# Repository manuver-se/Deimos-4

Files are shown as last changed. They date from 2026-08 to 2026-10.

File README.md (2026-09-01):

# Deimos-4 | Analog, DIY rhythm machine

Welcome to the official repository for the **Deimos-4**, a DIY, analog 4-voice drum machine with step-sequencer powered by an Arduino Nano.

Designed for both live jamming and having lots of fun, the Deimos-4 combines classic analog circuitry based on the original 606 and 808 circuits, a 16-step sequencer, an intuitive interface, basic sync out connectivity, and an expansion header for future expansions.

A7C14604-E1E4-4C48-A52F-A848609FFAB7_1_105_c

---

## Overview & Features

* **4 analog drum voices:** Dedicated circuits for Kick, Snare, Closed Hi-Hat (CHH), and Open Hi-Hat (OHH) with choke logic for the hihats. The decay and pitch for kick and snappy and pitch for snare are changeable. The levels of each individual drum voice can also be adjusted with trimpots.
* **16-step sequencer:** Divided across 4 pages (4 steps per page) with per-step pattern memory. There are controls for tempo, swing and sequencer length. Individual drum voices are mutable while the sequence is running.
* **Dual operating modes:**
  * **Live mode:** Finger-drum live or over a running background sequence.
  * **Sequencer mode:** Full step-editing control per voice and per step.
* **EEPROM memory:** Automatic pattern saving using the internal EEPROM memory from the Arduino Nano.
* **Sync out:** Jumper configurable sync out with **opto-isolated S-trig** (short-to-ground triggers used for some vintage synths) or **direct 5V V-trig** (for most modern gear, eurorack).

---

## Test points & Expansion header

For DIY builders, modders, and audio hackers, the Deimos-4 PCB includes dedicated test points for diagnostics as well as an onboard expansion header for custom hardware modifications.

### Onboard test points
* **Noise generators:** Dedicated test/tap points for both **White Noise (noice noize)** and **Metallic Noise (Beehive(ing)_Noizzze)** (used for snare snappy and hihat circuits respectively) 
* **Hidden tom circuit:** Test/tap point for the snare without snappy
* **Voltage rails:** Testpoints for 9V, digital 5V, 4.5V and GND rails
* **Individual voice tap points:** Test/tap points for the raw audio signal of each drum voice (Kick, Snare, CHH, OHH) before it reaches the master summing stage.
* **Triggers:** 4 testpoints for triggering drum voices: Kick trigger (BD_TR), Snare trigger (SN_TR), Hihat trigger (to trigger open hihat; HH_TR) and a gate testpoint (HH_GT) that together with the Hihat trigger, triggers the closed hihat.

### Hardware expansion header
The PCB design also features an 8 pin header designed for hardware expansions and modifications. This connector includes:
* **Separate outs:** Tap each drum voice individually to route them to dedicated external audio jacks, outboard effects, or separate mixer channels.
* **Power rails:** Exposes internal power rails (9V, 4.5V and GND) to power future expansion boards or external mod circuits.
* **Master out & To jack input:** Access to master out and jack input. These two pins should be connected by default.

## Manual & Documentation

For detailed information on drummachine history, kit assembly or operating manual, please refer to the temporary user manual included in the repository. For now there only is a version Dutch, but the English version is coming soon.

* **[Handleiding-ned.pdf]** 

---

## Terms of use & Licensing

If you made it until here, I thank you for your interest in the Deimos-4 drummachine project! Please take a moment to review the guidelines regarding the hardware, software, and documentation shared in this repository:

* **Firmware & Documentation:** All source code, schematics, and documentation provided here are free for personal, educational, and non-commercial use. You are welcome to study, modify, and flash the code for your own personal DIY builds.
* **PCB design files:** Please note that the KiCad PCB layout files and Gerbers aren't included in this repository and will not be released publicly. The Deimos-4 hardware design is proprietary and will be manufactured and sold as a commercial DIY kit in the future.
* **Commercial restriction:** You may not use the documentation, code, or hardware schematics from this repository for any commercial purposes, product manufacturing, or resale without explicit permission.

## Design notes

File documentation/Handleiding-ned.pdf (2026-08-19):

## Deimos-4 DIY, Analog rhythm machine

## Part of the Manuverse

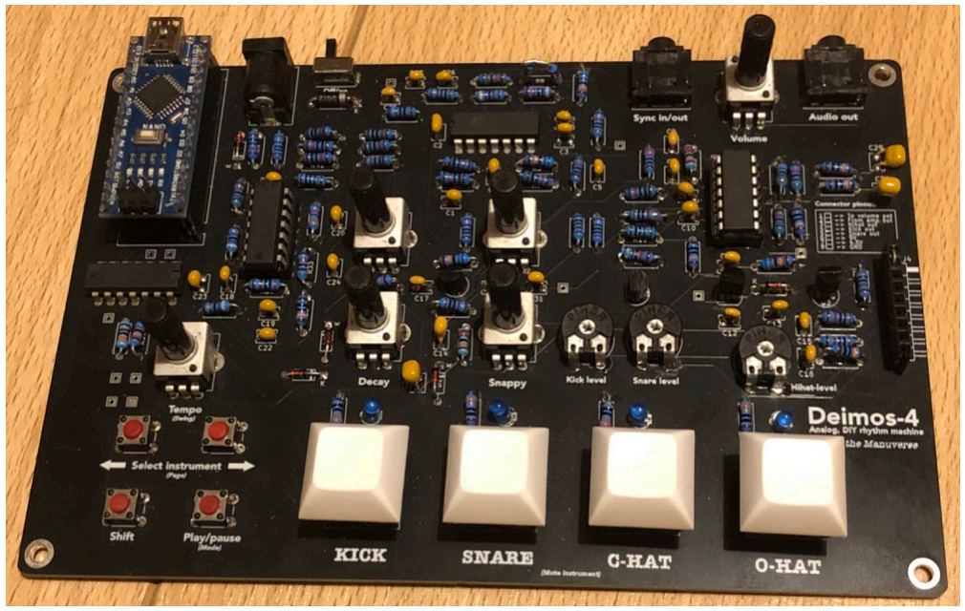
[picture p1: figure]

# Handleiding

# Inhoud

## 1. Korte geschiedenis van de drummachine • De 1e drummachine (3)

- Zoektocht naar een ritmische begeleiding (3)
- Eerste programmeerbare drummachine (4)
- Gouden decennium (4)
- Drummachines van toen naar nu (5)

## 2. Assemblage van de kit • BOM (6)

- Voorbeeld (voor een condensator) (6)
- BOM (voor echt!!!) (7)
- Voorbeeld (voor een weerstand) (8)
- Diodes, transistors en IC chips (8)
- Grote en mechanische componenten (9)

## 3. Bediening van de drummachine • De Knoppen & De Koplampen (10)

- Live Modus vs. Sequencer Modus (10)
- Tempo, Swing & ‘Catch-Up’ (12)
- Extra Pro-Tricks voor de Geavanceerde Beatmaker (12)
- Onder voorbehoud (Rev2.1): De Sync-Out (Jumper Instellingen op de PCB) (13)

## 4. Documentatie (14)

# Korte geschiedenis van de drummachine

De drummachine is vandaag de dag niet meer weg te denken uit genres als hiphop, pop, techno, dance, R&B en vele andere. De opzwepende ritmes die ze kunnen produceren met hun karakteristieke geluid zijn geliefd bij vele muzikanten en producers. In dit hoofdstuk gaan we zo’n 100 jaar terug in de tijd om te kijken hoe drummachines zijn geëvolueerd tot de elektronische percussie-instrumenten die we nu kennen.

### De 1e drummachine

De oorsprong van de drummachine brengt ons opvallend
ver terug in de tijd, naar het jaar 1930 om precies te zijn. De Amerikaanse avant-garde componist Henry Cowell was op zoek naar een manier om complexe, polyritmische patronen te spelen die voor een menselijke muzikant vrijwel onmogelijk waren. Hij schakelde de hulp in van Leon Theremin, de uitvinder van de gelijknamige Theremin, om samen de ‘rhythmicon’ (Fig. 1.1) te ontwerpen. Dit indrukwekkende instrument, dat door velen wordt beschouwd als de allereerste drummachine ter wereld,
werkte zowel optisch als mechanisch door middel van een
draaiende schijf met gaatjes die werd uitgelezen door

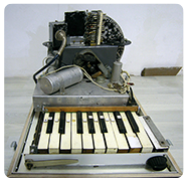
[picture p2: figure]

lichtsensors die de plotse lichtinval bij passage van een gaatje registreerden. Hoewel de Rhythmicon zijn tijd ver vooruit was, duurde het tot 1959 voordat de eerste commerciële drummachine op de markt verscheen: de Wurlitzer Sideman. In tegenstelling tot moderne drummachines was dit een gigantische, houten kast die werkte met vacuümbuizen en een roterende schijf met pinnen die functioneerde als een soort muziekdoos. Hij bevatte tien elektronisch gegenereerde percussiegeluiden en bood voorgeprogrammeerde ritmes zoals de ‘waltz’ en de ‘cha cha’.

### Zoektocht naar een ritmische begeleiding

In het begin van de jaren zestig was een jonge Japanse uitvinder, Ikutaro Kakehashi, diep geïntrigeerd geraakt door de Wurlitzer Sideman. Hij richtte Ace Electronic Industries op en begon met de ontwikkeling van kleinere ritmeboxen. Dit leidde in 1967 tot een enorme doorbraak: de FR-1 Rhythm Ace. Het was de allereerste ritme-machine op de markt met een ritmespeler en bovenal: transistor gebaseerde circuits in plaats van de plaatsnemende en zware vacuüm tubes.
Dit transistorontwerp was een gigantische stap voorwaarts in betrouwbaarheid en draagbaarheid. De Rhythm Ace was enorm populair, in zo'n grote mate dat de Hammond Organ Company besloot het systeem te adopteren en zelfs in te bouwen in hun orgels! Kakehashi ontwierp na de FR-1 nog tal van andere gelijkaardige drummachines onder Ace Electronic die telkens ook fungeerden als ritmische begeleiding voor organisten en muzikanten.

Fig. 1.1: Rhythmicon
Andrey Smirnov via asmir.info

### Eerste programmeerbare drummachine

Hoewel de vroege transistor-apparaten een succes waren, konden muzikanten alleen meespelen met voorgeprogrammeerde ritmes. De wens om zelf de controle te nemen leidde in 1972 tot de Eko ComputeRhythm (Fig. 1.2), die wordt beschouwd als de eerste echt programmeerbare drummachine ter wereld. Binnen een volledig analoog circuit stelde de ComputeRhythm muzikanten in staat om zelf zes verschillende drumvoices te programmeren in een raster van 16 stappen. Deze machine was zijn tijd zo ver vooruit dat er vandaag de dag wereldwijd naar schatting nog maar 15 werkende exemplaren van bestaan.

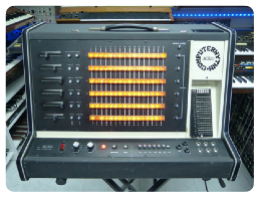
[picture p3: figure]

### Gouden decennium

De overgang van de jaren 70 naar 80 markeert een ware explosie aan innovatie voor elektronische instrumenten, zowel voor drummachines als synthesizers. Herinner je je Ikutaro Kakehashi nog? In 1972 richtte hij het inmiddels legendarische merk Roland Corporation op.
CR-78: Met de introductie van de Roland CR-78 in 1978 werd voor het eerst chiptechnologie gebruikt, wat muzikanten in staat stelde patronen te programmeren én op te slaan in het geheugen. Dit iconische apparaat kreeg grote bekendheid door artiesten als Blondie en Phil Collins, die de unieke sound omarmden.
TR-808: Twee jaar later kwam de Roland TR-808 Rhythm Composer op de markt. Met zijn zware, diepe analoge kickdrum en karakteristieke cowbell klonk de 808 niet echt als een realistisch drumstel, wat er initieel voor zorgde dat het apparaat flopte. Toen de 808 echter jaren later goedkoop op de tweedehandsmarkt belandde, pikten slaapkamerproducers het op en werd de TR-808 dé ruggengraat van hiphop en elektronische dansmuziek. Het is ook diezelfde 808 (samen met de TR606, een versimpelde en goedkopere versie van de 808) die de inspiratie vormde voor de Deimos-4.
LinnDrum: Tegelijkertijd (in 1980) introduceerde de Amerikaanse ingenieur Roger Linn de Linn LM-1, de allereerste drummachine die gebruikmaakte van digitale samples (akoestische drumopnames). Dit resette de industrie: ineens kregen drummachines een realistische klank. Zijn opvolger, de goedkopere LinnDrum uit 1982, domineerde vrijwel de volledige popmuziek uit de vroege jaren 80 en is te horen op monsterhits van o.a. Prince en The Human
League.
Oberheim DMX (Fig. 1.3): Kort daarop kwam
synthesizerpionier Oberheim met de concurrent: de Oberheim DMX. Dit 12-bit sample-based instrument klonk luchtiger en realistischer, wat het geluid definieerde van tracks als New Order's Blue Monday.
Linn 9000: In 1984 zette Roger Linn een nieuwe standaard met de Linn 9000, dat fungeerde als de eerste geïntegreerde digitale drummachine met een
ingebouwde MIDI-sequencer en drukgevoelige rubberen

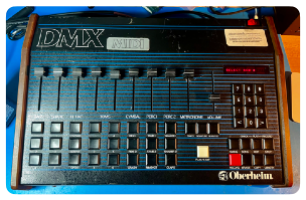
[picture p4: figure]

pads, functies die later industriestandaarden zouden worden.

Fig. 1.3: Oberheim DMX
wikipedia.org/wiki/Oberheim_DMX

Fig. 1.2: EKO
Computerhythm MKIII
reverb.com/news

TR-909: In 1983 reageerde Roland met de TR-909. Waar eerdere Roland drummachines volledig analoog klank opwekten, gebruikte de 909 een hybride systeem: analoge circuits voor de kick, snare, rim, clap en toms gecombineerd met digitale samples voor de cymbals en hi-hats. Helaas flopte deze drummachine ook wanneer deze op de markt kwam omdat iedereen wild was van de nieuwe, digitale drummachines omdat ze veel realistischer klonken. Maar naar klassieke Roland traditie zijn er jonge muzikanten die enkele jaren later 909’s tegenkwamen op de tweedehandsmarkt om nieuwe genres als techno en house uit de grond te stampen.
Akai MPC: Aan het einde van het decennium, in 1988, bundelde Roger Linn zijn krachten met het Japanse Akai. Het resultaat was de Akai MPC60. Dit geïntegreerde systeem fungeerde als sampler, drummachine en sequencer in één, uitgerust met de beroemde 4x4 grid van responsieve pads.

### Drummachines van toen naar nu

Toen computers in de late jaren 90 geavanceerder werden, nam de vraag naar hardware drummachines af ten gunste van software en VST-plugins. Toch blijft de drang naar een instrument dat je echt kan aanraken en bespelen reëel en het is vanuit dat opzicht dat ik besloot om de Deimos-4 te ontwerpen…

# Assemblage van de kit

Ziezo, nu je volledig bent ondergedompeld in de wonderlijke wereld van de drumcomputers, wil je er zelf waarschijnlijk ook één bouwen. Met deze kit heb je alvast alles in huis om een geweldige drummachine te bouwen.

### BOM

Een BOM (=Bill of Materials) is een lijst met een overzicht van alle componenten, hun aantallen en een referentie voor waar ze op de pcb horen geplaatst te worden. De handleiding voor de assemblage van de kit is grotendeels gebaseerd op de BOM, dus we gaan hier nog vaak op terugkomen. Op de volgende pagina staat ’m, maar om papierverspilling tegen te gaan gaan we al verder met instructies op deze pagina.
Eerst en vooral, hoe gebruik je zo’n BOM? Het is eigenlijk niet zo moeilijk eens je het door hebt. In de kolom ‘value/component’ staan alle componenten met hun eventuele waarde. In de kolom ernaast, ‘reference’, staan de pcb plaatscodes (geen idee hoe je dat in het Nederlands noemt, dus heb ik het maar een naam gegeven ;-) ). De meest rechtse kolom, ‘Qty’, zegt hoeveel er van een bepaald component zitten in deze kit.
De componenten staan min of meer in soldeervolgorde: begin met de keramische condensators, vervolgens de weerstanden, diodes en transistors, daarna de ic-chips en trimmers en om af te ronden de schakelaars, connectoren, potmeters en de Arduino.

### Voorbeeld (voor een condensator) (Fig. 2.1)

Ik stel voor dat we stap voor stap met behulp van de BOM een condensator plaatsen en solderen die kan dienen als voorbeeld voor de andere
condensatoren. We zullen de 2,2 nF’s plaatsen die bovenaan in de BOM staan. Bij ‘reference’ ernaast kan je zien dat ze op C12, C13 en C17 moeten komen.

Plaats de condensatoren op de juiste
plek. Je moet geen rekening houden

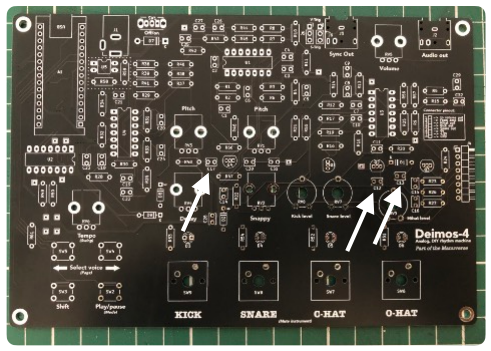
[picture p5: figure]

met polariteit aangezien alle condensatoren in deze kit keramisch zijn. Plooi de beentjes langs de achterkant om om te voorkomen dat ze eruit vallen wanneer je de pcb omdraait. Dan kan je de componenten vastsolderen en daarna de uiteinden die nog uitsteken afknippen met een kniptang. Opgelet: helaas heb ik door het plaatsen van bijbestellingen voor componenten soms andere formaten, waardoor niet elke condensator meteen ‘past’ op de footprint. In dit geval moet je de beentjes wat vervormen met een knijptang totdat ze wel passen, sorry…

Fig. 2.1: C12, C13 en C17 aangeduid op pcb

Deimos-4 Rev2.1 BOM

Value/component | Reference | Qty
2.2nF (Condensator) | C12,C13,C17 | 3
3.3nF (Condensator) | C15,C16,C26,C27 | 4
10nF (Condensator) | C25 | 1
15nF (Condensator) | C3,C4,C18 | 3
33nF (Condensator) | C5,C11 | 2
39nF (Condensator) | C8,C9 | 2
47nF (Condensator) | C30,C31 | 2
100nF (Condensator) | C1,C6,C7,C10,C19,C20,C21,C22,C23,C24 | 10
220nF (Condensator) | C2 | 1
1uF (Condensator) | C14 | 1
10uF (Condensator) | C28,C29,C32 | 3
47R (Weerstand) | R28 | 1
220R (Weerstand) | R14 | 1
330R (Weerstand) (1x Opt) | R51,R52,R53,R54,R58 | 5 (4)
680R (Weerstand) | R42 | 1
1K (Weerstand) (1x Opt) | R19,R21,R29,R43,R46,R55,R59,R61 | 8 (7)
3.3K (Weerstand) | R49 | 1
4.7K (Weerstand) | R45 | 1
10K (Weerstand) | R1,R2,R4,R6,R12,R36,R37,R38,R39,R40,R41 | 11
20K (Weerstand) | R11,R17,R23,R24,R26,R30,R47,R56 | 8
33K (Weerstand) | R31 | 1
47K (Weerstand) | R7,R16,R32 | 3
51K (Weerstand) | R33,R57 | 2
68K (Weerstand) | R25,R34,R44 | 3
100K (Weerstand) | R5,R9,R15,R18,R27,R35,R48 | 7
220K (Weerstand) | R13,R22 | 2
680K (Weerstand) | R3,R8,R10,R20,R50,R60 | 6
1N4148 (Diode) | D1,D2,D8,D9 | 4
1N5819 (Diode) | D7 | 1
LED (Diode) | D3,D4,D5,D6 | 4
2N3904 (Transistor) | Q1,Q2,Q3,Q4 | 4
LM324 (IC chip) | U1,U3 | 2
CD4066BE (IC chip) | U2 | 1
CD40106 (IC chip) | U4 | 1
LTV817 (IC chip) (Opt) | U5 | 1 (0)
10K (Potmeter-trimmer) | RV7,RV8,RV9 | 3
Power Switch (Schakelaar) | SW1 | 1
Menu Switches (Schakelaar) | SW2,SW3,SW4,SW5 | 4
Play Switches (Schakelaar) | SW6,SW7,SW8,SW9 | 4
Audio Jack (Connector) | J2,J3 | 2
8 Pin Conn (Connector) | J4 | 1
DC Jack (Connector) | J1 | 1
10K (B103) (Potmeter) | RV1,RV2,RV5,RV6 | 4
100K (A/B104) (Potmeter) | RV3 (B104),RV4 (A104) | 2
Arduino Nano (Microcontroller) | A1 | 1

### Voorbeeld (voor een weerstand)

Nu gaan we hetzelfde doen voor een weerstand. We zullen dit doen voor de weerstand van 47 Ohm die hoort bij footprint R28 (Fig. 2.2).

Begin met het omplooien van de beentjes van de weerstand zo dicht mogelijk bij de ‘body’ (het blauwe gedeelte). Zorg er uiteraard voor dat de twee beentjes in de zelfde richting zijn omgeplooid. Daarna kan je de weerstand op de juiste footprint
plaatsen. Ook nu kan je aan de
achterkant de beentjes omplooien om

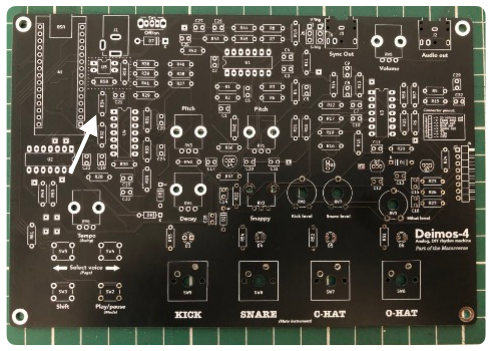
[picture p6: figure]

te voorkomen dat de weerstand eruit zou vallen. Soldeer en knip opnieuw de uiteinden af met een kniptang. (Het is nogal veel van hetzelfde, ik weet het ;-) )

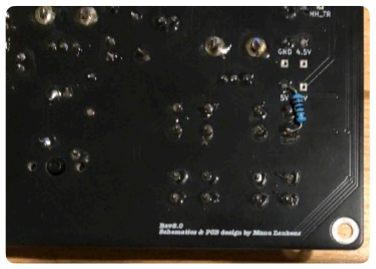
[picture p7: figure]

Opgelet (geldt enkel voor Rev2.0): R61 (1K)
staat niet op de pcb zoals die bij Rev2.1 erop
staat. Je moet deze weerstand dus nog zelf
solderen tussen 2 componenten zonder dat er een footprint voor voorzien is. Je soldeert hem tussen het 5V testpunt en een van de onderste twee beentjes van de knop met de pijl naar links. Bekijk ook even de afbeelding hiernaast om dit beter te zien (Fig. 2.3).

### Diodes, transistors en IC chips

Nu zijn we aangekomen bij het solderen van
componenten waarbij de polarisatie of m.a.w. de
richting van het component dat geplaatst wordt, belangrijk is. Ik ga dit voor elk van deze onderdelen even bespreken.
Diodes (Fig. 2.4) moeten ongeveer zoals weerstanden worden geplaatst, maar alleen is het belangrijk dat de kant met de zwarte streep (voor de 1N4148) of de witte streep (voor de 1N5819) van de diode overeen komt met de kant van de streep op de pcb. De platte kant van een LED moet overeenkomen met de kant van de vierkante soldeerpad.
Transistors moeten simpelweg geplaatst worden met de platte kant van de transistor aan dezelfde kant als de platte kant van de footprint. Let goed op dat er bij het solderen geen verbinding ontstaat tussen de beentjes van de transistor aangezien de

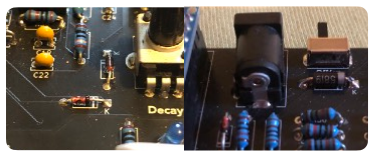
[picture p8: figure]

pads vrij dicht bij elkaar liggen voor de transistors.

Fig. 2.2: R28 aangeduid op pcb

Fig. 2.3: Gebridgede weerstand tussen 5V en onderste beentje knop naar links

Fig. 2.4: D8 en D9 (1N4148) met strepen overeenkomstig (links) D7 (1N5819) met streep
overeenkomstig (rechts)

Opgelet: helaas heb ik door het plaatsen van bijbestellingen voor componenten soms andere formaten, waardoor niet elke transistor meteen ‘past’ op de footprint. In dit geval moet je de beentjes wat vervormen met een knijptang totdat ze wel passen, sorry…

IC chips zijn al op voorhand door mij in hun socket gestoken om frustraties te voorkomen (ik heb al wel een paar chips kapot gedaan door ze in hun socket te steken… Misschien ligt dat aan mij, maar de sockets lijken nogal taai). Om de chips te plaatsen moet je goed opletten dat de kant met het hapje uit de chip overeen komt met de kant van het hapje uit de footprint. Let ook op dat je de soldeerbout niet te lang houdt op eenzelfde plaats om hitteschade aan de chip te voorkomen. Eventueel kan je in plaats van telkens de pin naast de juist gesoldeerde pin te solderen, de pin schuinover de juist gesoldeerde pin solderen. Als je het sync circuit op een Rev2.1 zou maken (dit circuit is voorlopig nog niet getest voor Rev2.1, maar ik ga dat zo snel mogelijk doen => op voorbehoud…), moet het bolletje op de LTV817 boven de rechthoekige soldeerpad komen.

### Grote en mechanische componenten

Alle componenten die nu nog overschieten zijn groot en/of (elektro)mechanisch. Ze wijzen zich grotendeels zelf uit om te solderen. Ik raad echter wel aan om min of meer de soldeervolgorde van de BOM te hanteren. Voor sommige componenten moet ik nog wel een klein beetje uitleg geven:
Voor de 8 pin connector is het heel belangrijk dat het blauwe tchoupke op de bovenste twee pinnen staat en niet op de onderste, anders kabaaaam => KORTSLUITING!!!
Op de onderkant van de potmeter staat een kleine ‘code’. In deze kit zitten er 4 B103’s (10K lineair), een B104 (100K lineair) en een A104 (100K logaritmisch). Het is belangrijk dat die op de juiste plek komen, maar dat spreekt natuurlijk voor zich. In de BOM heb ik ook nog in een andere kleur (vooral voor A104 en B104) aangegeven welke waar moet komen.
Voor de Arduino Nano heb ik 2 socketlatjes (of hoe de **** dat ook mag heten… sorry ik voor het taalgebruik, een handleiding schrijven duurt langer dan gedacht en ik heb geen zin meer, maar ik moet die toch op tijd afkrijgen voor jullie ;-) ) van 15 pinnen voorzien. Soldeer deze eerst op de pcb en steek later daarna de Arduino Nano hierin.

Voor Rev2.0 kits: Gebruik een lang afgeknipt beentje om een bridge connectie te maken tussen 2 GND punten zoals in (Fig. 2.5). De bridge moet komen tussen het onderste beentje van de 8 pin connector en het linkerbeentje van R23.

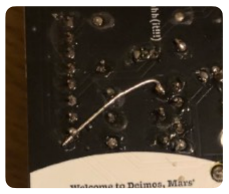
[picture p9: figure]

Fig. 2.5: Bridge
tussen GND punten

# Bediening van de drummachine

Hier komt een heel tof door AI geschreven handleiding voor het gebruik van de drumcomputer. Veel succes ermee en mijn excuses hiervoor ;-).

Gefeliciteerd! Als je bij dit hoofdstuk bent aangekomen, is de kans groot dat je de soldeerbout veilig hebt opgeborgen, de rookmelder niet is afgegaan en alle componenten op de juiste plek zitten. Tijd voor het leukste gedeelte: herrie maken (of natuurlijk verfijnde elektronische muziek, net hoe je het zelf noemt).

In dit hoofdstuk leggen we je uit hoe je de drumcomputer bedient. Geen zorgen, je hebt geen brein van een NASA-ingenieur nodig om een strakke beat uit deze kast te trekken, maar er zitten een paar handige geheime toetsencombinaties in die je leven een stuk makkelijker maken.

### De Knoppen & De Koplampen

Laten we beginnen met een snelle rondleiding over het bedieningspaneel.

- 4 Drumknoppen met LED’s: Dit zijn je vier drumstemmen (van links naar rechts: Kick, Snare, Closed Hi-Hat, Open Hi-Hat). De LED's boven de knoppen laten precies zien wat er gebeurt.
- < en > Knoppen: Je navigatiepijlen om door je drumstemmen en pagina’s te bladeren.
- PLAY / STOP Knop: Start of stopt de sequencer. Blijft gewoon werken, in welke modus je ook zit.
- SHIFT Knop: De 'Zwitserse zakmes'-knop. Houd deze ingedrukt om secundaire functies te activeren.
- Draaiknop (Potmeter): Regelt je tempo, maar met SHIFT ingedrukt verandert 'ie in een swing-regelaar of een heuse sequencer-lengte-instel-knop!

### Live Modus vs. Sequencer Modus

De drumcomputer heeft twee hoofdmodi. Je wisselt tussen deze twee werelden door SHIFT ingedrukt te houden en op PLAY te drukken.

Als je wisselt, zie je een snelle lichtshow over de 4 LED’s:

- Van rechts naar links: Welkom in Live Modus!
- Van links naar rechts: Welkom in Sequencer Modus!

### 1. Live Modus (Jammen maar!)

In Live Modus transformeren de 4 drumknoppen in fysieke drumpads.

- Druk op een knop en de analoge drum wordt meteen afgevuurd.
- Het mooie is: Als de sequencer op de achtergrond loopt, kun je er gewoon met je vingers overheen drummen.
- Visuele magie: Als de sequencer een drum triggert, licht het LED’je zachtjes op. Druk je er zelf met je vingers op? Dan flitst 'ie op maximale helderheid. Zo zie je precies het verschil tussen de machine en jouw eigen ritmegevoel.

### 2. Sequencer Modus (Beats Programmeren)

Dit is de werkbank waar je patronen bouwt van maximaal 16 stappen.

Omdat we 16 stappen hebben en slechts 4 fysieke knoppen, is het patroon opgedeeld in 4 pagina’s van elk 4 stappen:

- Pagina 1: Stap 1 t/m 4
- Pagina 2: Stap 5 t/m 8
- Pagina 3: Stap 9 t/m 12
- Pagina 4: Stap 13 t/m 16

Zo programmeer je een patroon:

### 1. Kies je drumstem: Druk op < of > om te wisselen tussen Kick, Snare, Closed Hat

of Open Hat. De LED’s knipperen kort om te laten zien welke stem je geselecteerd hebt.

### 2. Kies je pagina: Houd SHIFT ingedrukt en druk op < of > om naar Pagina 1, 2, 3 of

4 te gaan. De LED’s lichten even op om te laten zien op welke pagina je bent.

### 3. Plaats je stappen: Druk op een van de 4 drumknoppen om een stap AAN of UIT te

zetten.

### 4. Druk op PLAY: En luister hoe je beat tot leven komt!

Geen opslaan-stress: Elk stapje dat je aan- of uitzet wordt meteen automatisch opgeslagen in het interne geheugen (EEPROM). Als je de drumcomputer uitzet en morgen weer aandoet, staat je beat er nog exact zo in!

### Tempo, Swing & 'Catch-Up'

Geen zin in een stijve, robotachtige beat? Tijd om aan de grote knop te draaien.

- Tempo aanpassen (+/- 40 - 160 BPM): Draai simpelweg aan de potmeter.
- Swing toevoegen (0% - 50%): Houd SHIFT ingedrukt en draai aan de potmeter. Hiermee schuif je de oneven stappen een klein beetje op voor een heerlijke 'human touch' of Shuffle-groove.

"Hé, mijn tempo springt niet meteen!" (Soft-Takeover)

Als je aan de knop draait terwijl je SHIFT ingedrukt houdt (voor Swing) en daarna SHIFT loslaat, staat de knop fysiek natuurlijk op een andere plek dan waar je tempo gebleven was.

Om te zorgen dat je muziek niet plotseling naar 160 BPM schiet als je de knop aanraakt, gebruikt de drumcomputer Soft-Takeover. Dit betekent dat je de knop eerst even fysiek 'voorbij' de oude waarde moet draaien. Pas als de knop de huidige instelling kruist, grijpt 'ie 'm vast. Geen schokkende tempo-sprongen meer op het podium!

### Extra Pro-Tricks voor de Geavanceerde Beatmaker

Sporen Muten (Mute)

Wil je tijdens een jam even de Kick weglaten voor een dramatische 'drop'?

- Hoe werkt het: Houd SHIFT ingedrukt en druk op een van de 4 drumknoppen.
- Dit werkt in zowel Live- als Sequencer Modus.
- De Live Bonus: Als een spoor gemute is, zal de sequencer die drum niet meer afspelen. Maar jij kunt er in Live Modus nog steeds met je vingers op drummen! Perfect om even handmatig een ander ritme over een gemute spoor te spelen.

Patroonlengte Aanpassen (1 t/m 16 stappen)

Wil je een vreemde maatsoort maken (zoals een 3/4 maat of een 7-step loop)? Dat kan, zelfs terwijl de sequencer gewoon doorspeelt!

- Hoe werkt het: Houd SHIFT + < + > tegelijk ingedrukt en draai aan de potmeter.
- De LED’s laten zien hoe lang je sequence is (welke pagina en welke stap). Het zacht schijnende ledje geeft aan op welke pagina je zit en de felle toont op welke stap precies.

Patroon Wissen (Clear)

Soms slaat de creativiteit door en wil je gewoon met een schone lei beginnen.

- Hoe werkt het: Houd in Sequencer Modus de knop SHIFT ingedrukt en druk alle 4 de drumknoppen tegelijk in.
- Alle LED’s knipperen 3 keer snel. Het patroon van álle instrumenten is nu gewist en eventuele mutes worden automatisch opgeheven zodat je meteen nieuw geluid hoort.

### Onder voorbehoud (Rev2.1): De Sync Out (Jumper Instellingen op de PCB)

Aan de achterkant van je drumcomputer zit een 3.5mm Sync Out-jack. Hiermee kun je andere apparaten (zoals Eurorack synthesizers, Korg Volca's of vintage apparatuur) strak mee laten lopen op het tempo van jouw drumcomputer.

Omdat de modulaire wereld helaas twee verschillende standaarden gebruikt, zitten er op de printplaat (PCB) twee 3-pin footprints naast de Sync-jack om te configureren door twee jumper te solderen tussen de corresponderende pinnen:

### 1. V-Trig Mode (Jumpers op Pinnen 1 & 2 - BOVEN): Stoot een krachtige +5V puls uit

de jack. Dit is de standaard voor 99% van alle moderne gear.

### 2. S-Trig / Opto Mode (Jumpers op Pinnen 2 & 3 - ONDER): Gebruikt de ingebouwde

LTV-817 optocoupler. De jack wordt volledig losgekoppeld van de interne aarding van je drumcomputer. Het werkt als een zwevende licht-schakelaar die de ingang van een vintage synth naar de grond trekt. Geen brom, geen ground loops, geen vreemde vervormingen van je analoge drumgeluiden!

# Documentatie

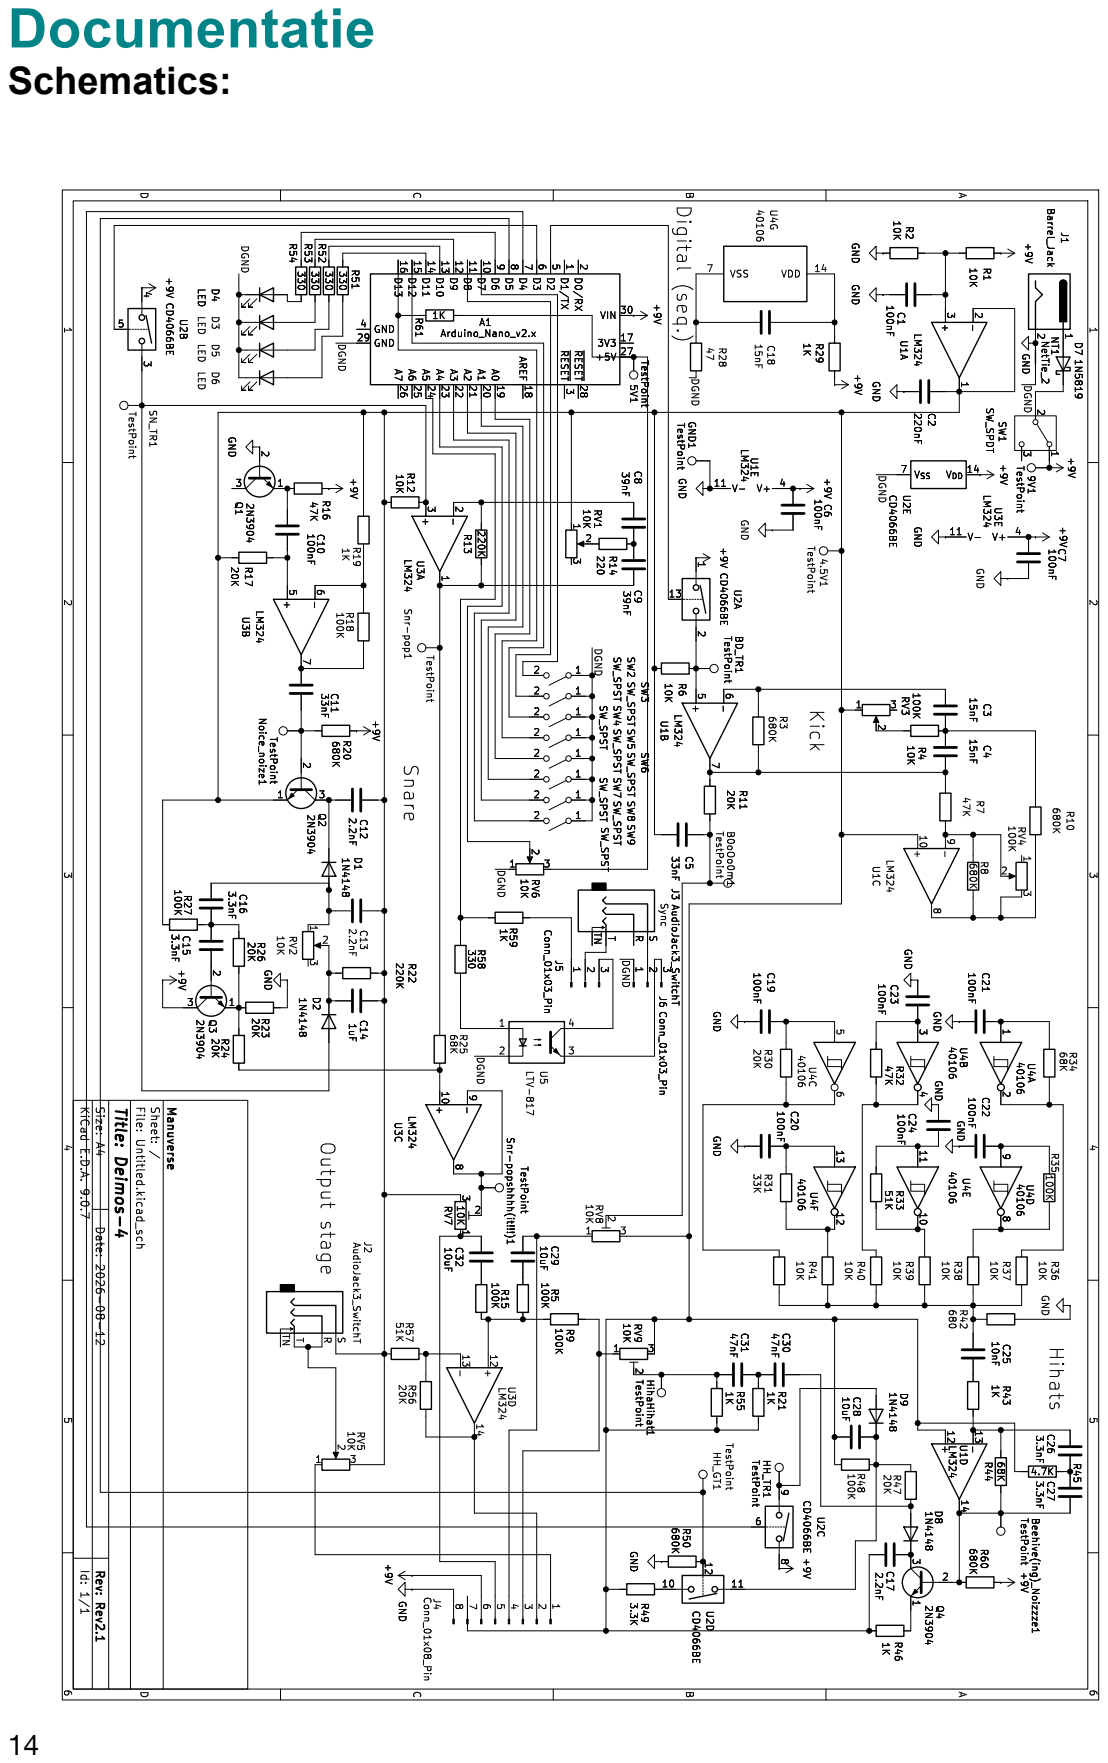
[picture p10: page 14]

### Arduino Nano Pinout:

D2 -> Kick trigger uitgang (15ms; 5V -> 9V door CD4066)
D3 -> Snare trigger uitgang (15ms; 5V -> 9V door CD4066)
D4 -> Hi-hat trigger uitgang (15ms; 5V -> 9V door CD4066)
D5 -> Closed hi-hat gate uitgang (high when triggering chh, low when triggering ohh; 5V -> decay short path door CD4066)
D6 -> Snare LED uitgang (PWM)
D7 -> Play/pause knop ingang
D8 -> Shift knop ingang
D9 -> Kick LED uitgang (PWM)
D10 -> Closed hi-hat LED uitgang (PWM) D11 -> Open hi-hat LED uitgang (PWM) D12 -> Pijl rechts (>) knop ingang
D13 -> Pijl Links (<) knop ingang
A0 -> Open hi-hat drumpad ingang
A1 -> Closed hi-hat drumpad ingang
A2 -> Snare drumpad ingang
A3 -> Kick drumpad ingang
A4 -> Potmeter ingang (tempo/swing/lengte)
A5 -> Master sync uitgang (elke puls 15ms; 5V pulsen voor S-trig, short to gnd pulsen voor V-trig)

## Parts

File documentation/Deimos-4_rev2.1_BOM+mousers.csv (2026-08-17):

Reference | Value | Qty | Mouser Part Number/Link
C12, C13, C17 | 2.2nF | 3 | 80-C320C222K5R
C15, C16, C26, C27 | 3.3nF | 4 | 80-C320C332K5R
C25 | 10nF | 1 | 80-C320C103K5R
C3, C4, C18 | 15nF | 3 | 80-C320C153K5R5
C5, C11 | 33nF | 2 | 80-C320C333K5R
C8, C9 | 39nF | 2 | 80-C320C393K5R
C30, C31 | 47nF | 2 | 80-C320C473K5R5TA-TR
C1, C6, C7, C10, C19, C20, C21, C22, C23, C24 | 100nF | 10 | 80-C320C104K5R5TATR
C2 | 220nF | 1 | 80-C320C224K5R
C14 | 1uF | 1 | 80-C320C105K5R5TA
C28, C29, C32 | 10uF | 3 | 80-C324C106K3R-TR
R28 | 47R | 1 | 603-MFR-25FRF52-47R
R14 | 220R | 1 | 603-MFR-25FRF52-220R
R51, R52, R53, R54, R58 | 330R | 5 | 603-MFR-25FRF52-330R
R42 | 680R | 1 | 603-MFR-25FRF52-680R
R19, R21, R29, R43, R46, R55, R59, R61 | 1K | 8 | 603-MFR-25FRF521K
R49 | 3.3K | 1 | 603-MFR-25FRF52-3K3
R45 | 4.7K | 1 | 603-MFR-25FRF52-4K7
R1, R2, R4, R6, R12, R36, R37, R38, R39, R40, R41 | 10K | 11 | 603-MFR-25FRF5210K
R11, R17, R23, R24, R26, R30, R47, R56 | 20K | 8 | 603-MFR-25FRF5220K
R31 | 33K | 1 | 603-MFR-25FRF52-33K
R7, R16, R32 | 47K | 3 | 603-MFR-25FRF52-47K
R33, R57 | 51K | 2 | 603-MFR-25FRF52-51K
R25, R34, R44 | 68K | 3 | 603-MFR-25FRF52-68K
R5, R9, R15, R18, R27, R35, R48 | 100K | 7 | 603-MFR-25FRF52100K
R13, R22 | 220K | 2 | 603-MFR-25FRF52-220K
R3, R8, R10, R20, R50, R60 | 680K | 6 | 603-MFR-25FRF52-680K
D1, D2, D8, D9 | 1N4148 | 4 | 512-1N4148
D7 | 1N5819 | 1 | 637-1N5819
D3, D4, D5, D6 | LED | 4 | 604-WP132XID
Q1, Q2, Q3, Q4 | 2N3904 | 4 | 512-2N3904BU
U1, U3 | LM324 | 2 | 595-LM324N
U2 | CD4066 | 1 | 595-CD4066BE
U4 | CD40106 | 1 | 595-CD40106BE
U5 | LTV-817 | 1 | 859-LTV-817
J2, J3 | Audio Jack | 2 | 490-SJ1-3524NG
J4 | 8 Pin Con | 1 | 571-5-146274-8, 855-M7581-05
J1 | DC Jack | 1 | 806-KLDX-0202-AC
SW1 | On/Off Switch | 1 | 179-SLW8645745ARAND
SW2, SW3, SW4, SW5 | Menu Switches | 4 | 611-PTS645SK432
SW6, SW7, SW8, SW9 | Voice Switches | 4 | 540-MX1A-C1NN
RV7, RV8, RV9 | 10K | 3 | 531-PT10V-10K-S
RV1, RV2, RV5, RV6 | 10K | 4 | 652-PTV09A-4025UB103
RV3, RV4 | 100K | 2 | 652-PTV09A-4025UA104,652-PTV09A-4025UB104
A1 | Arduino Nano | 1 | https://www.amazon.com.be/-/nl/AZDelivery-AZ-Nano-microcontroller-ATMEGA328-inbegrepen/dp/B01LWSJBTD
 | Power supply | 1 | https://www.amazon.com.be/dp/B0BGRF8H44

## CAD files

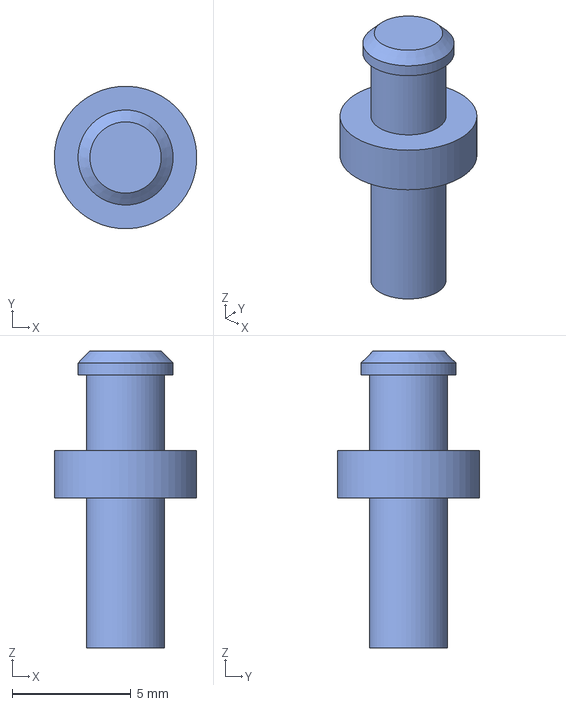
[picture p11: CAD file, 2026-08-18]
enclosure/withtext/Deimos-4 Drummachine - Button-arm_1.step
5.99 x 6.00 x 12.5 mm

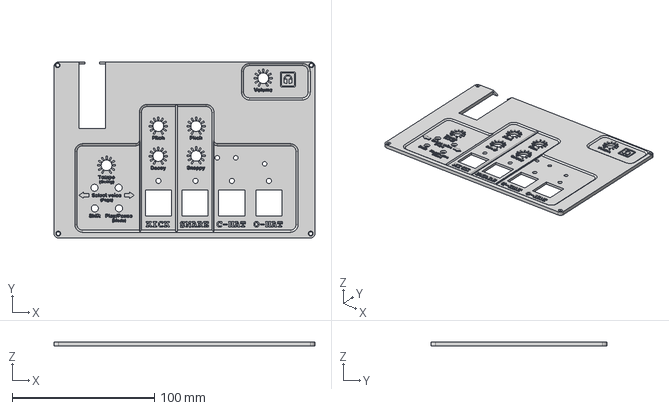
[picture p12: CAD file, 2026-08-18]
enclosure/withtext/Deimos-4 Drummachine - Top.step
183.3 x 123.5 x 3.00 mm

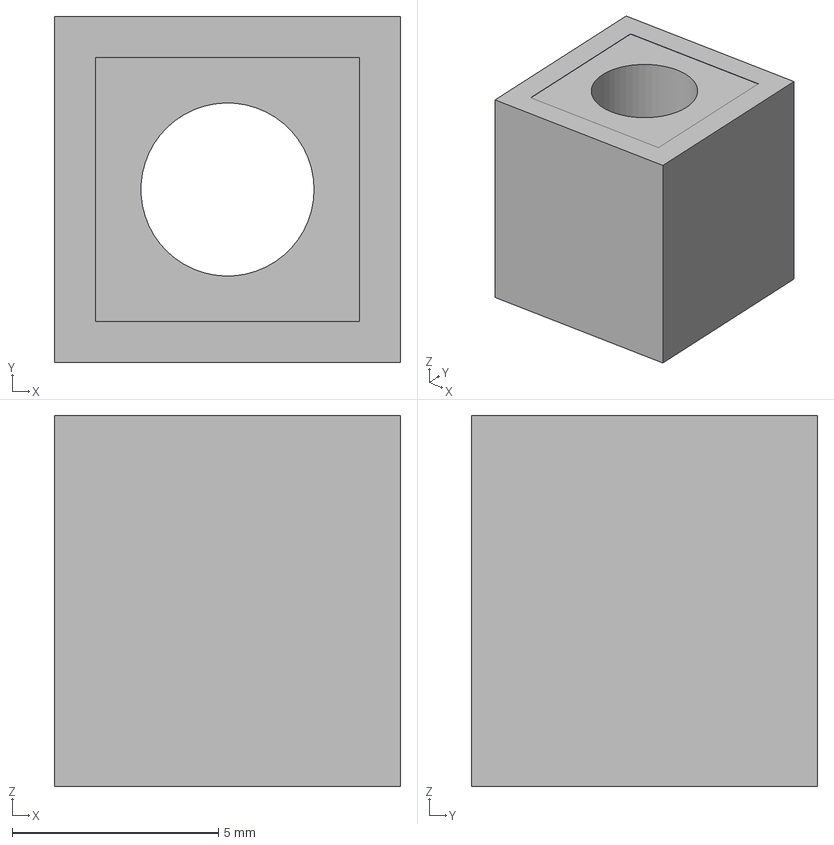
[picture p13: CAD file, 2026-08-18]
enclosure/withtext/Deimos-4 Drummachine - Button-body_1.step
8.40 x 8.40 x 9.00 mm

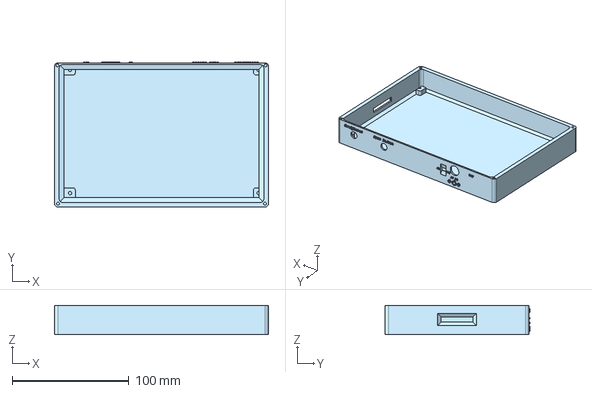
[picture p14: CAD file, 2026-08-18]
enclosure/withtext/Deimos-4 Drummachine - Body.step
183.3 x 124.3 x 25.0 mm

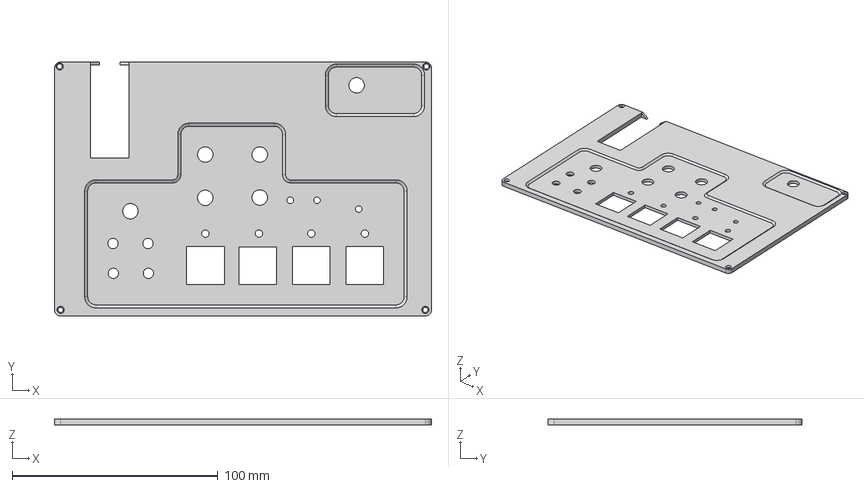
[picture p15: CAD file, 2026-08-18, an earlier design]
enclosure/notext/Deimos-4 Drummachine - Top.step
183.3 x 123.5 x 3.00 mm

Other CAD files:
enclosure/notext/Deimos-4 Drummachine - Button-arm_1.step
enclosure/notext/Deimos-4 Drummachine - Body.step
enclosure/notext/Deimos-4 Drummachine - Button-body_1.step

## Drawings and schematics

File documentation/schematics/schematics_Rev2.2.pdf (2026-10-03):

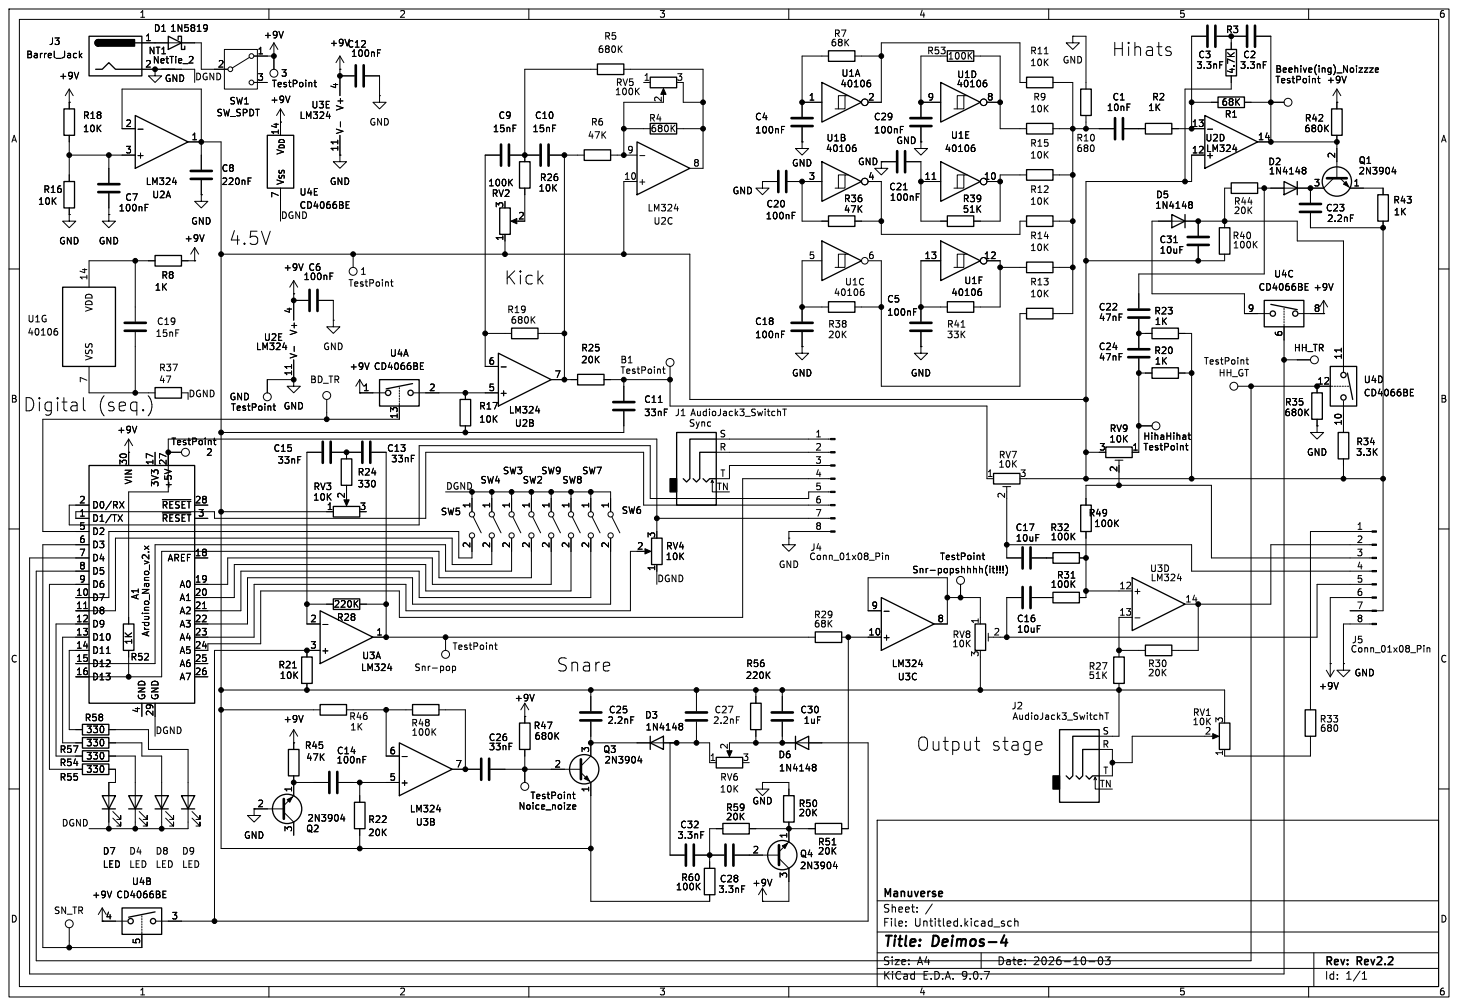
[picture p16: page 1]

J4Conn_01x08_Pin +
File: Untitled.kicad_sch Sheet: / Manuverse GND

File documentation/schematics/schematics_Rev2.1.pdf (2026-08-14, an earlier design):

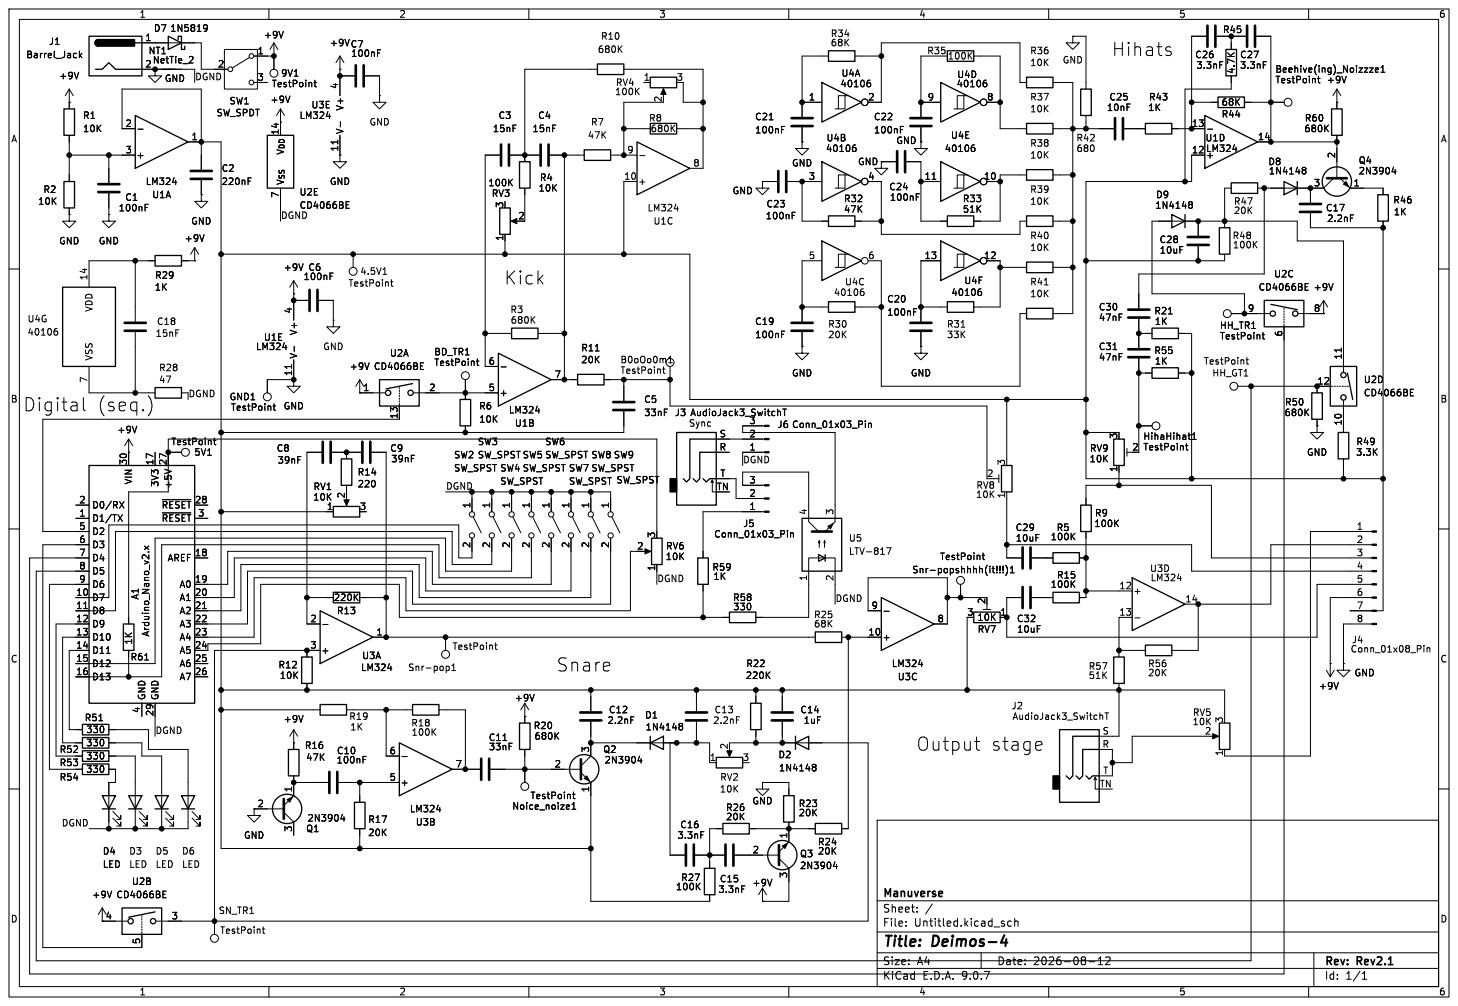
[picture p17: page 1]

Snr-popshhhh(it!!!)1 TestPoint U3C

File: Untitled.kicad_sch Sheet: / Manuverse

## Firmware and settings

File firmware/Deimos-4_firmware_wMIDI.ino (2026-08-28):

#include <EEPROM.h>

// --- HARDWARE PINS ---
const int kickOut = 2;
const int snareOut = 3;
const int hihatOut = 4;
const int closedHatGate = 5;

const int btnPlay = 7;
const int btnShift = 8;
const int btnLeft = 13; // Requires external 1k-2.2k pull-up to 5V
const int btnRight = 12;
const int potTempo = A4;
const int syncOut = A5; // Dedicated Sync Out Jack

const int btnDrums[4] = {A3, A2, A1, A0}; // Kick, Snare, CHH, OHH
const int ledDrums[4] = {9, 6, 10, 11};   // PWM capable

// --- LED SETTINGS ---
const int LED_BRIGHT = 255;
const int LED_DIM = 15;

// --- STATE VARIABLES ---
bool isLiveMode = true;
bool isPlaying = false;
int currentVoice = 0; // 0=Kick, 1=Snare, 2=CHH, 3=OHH
int currentPage = 0;  // 0 to 3 (Pages 1-4)
byte seqLength = 16;  
int currentStep = 0;

// Sequence Data [voice][step]
bool pattern[4][16] = {false};
bool muted[4] = {false, false, false, false};

// Timing & Swing
unsigned long lastStepTime = 0;
unsigned long stepInterval = 125; 
int swingAmount = 0; 
int savedPotVal = 0;

// Soft-Takeover (Catch-up) Variables
bool tempoLocked = false;
bool swingLocked = false;
bool lengthLocked = false;
bool lastShiftState = false;
bool lastLengthEditState = false;
bool wasShiftHeldForPot = false;

// Triggers (Hardware vs Visuals)
const int TRIG_LEN = 15;
unsigned long triggerStartTime[4] = {0, 0, 0, 0};
unsigned long visualTriggerTime[4] = {0, 0, 0, 0}; 
bool triggerActive[4] = {false, false, false, false};
bool gateClosed = true;

// Sync Trigger Variables
unsigned long syncTriggerStartTime = 0;
bool syncTriggerActive = false;

// Button Debouncing & State
bool lastDrums[4] = {false, false, false, false};
bool lastPlay = false;
bool lastLeft = false;
bool lastRight = false;
bool allPressedHandled = false;

unsigned long lastDrumTime[4] = {0, 0, 0, 0}; 
unsigned long lastNavTime = 0;
const int DEBOUNCE_DELAY = 30; 

// UI Animations
unsigned long voiceShowTimer = 0;
bool showingVoice = false;
unsigned long pageShowTimer = 0;
bool showingPage = false;
unsigned long modeShowTimer = 0;
bool showingMode = false;
bool modeScrollDir = true; 

// --- MIDI VARIABLES ---
byte midiState = 0;
byte midiCommand = 0;
byte midiNote = 0;
byte midiVelocity = 0;
byte midiClockCounter = 0;
bool useExternalClock = false;
unsigned long lastMidiClockTime = 0;

void setup() {
  pinMode(kickOut, OUTPUT);
  pinMode(snareOut, OUTPUT);
  pinMode(hihatOut, OUTPUT);
  pinMode(closedHatGate, OUTPUT);
  
  pinMode(syncOut, OUTPUT);
  digitalWrite(syncOut, HIGH); 

  pinMode(btnPlay, INPUT_PULLUP);
  pinMode(btnShift, INPUT_PULLUP);
  pinMode(btnLeft, INPUT_PULLUP);
  pinMode(btnRight, INPUT_PULLUP);

  for (int i = 0; i < 4; i++) {
    pinMode(btnDrums[i], INPUT_PULLUP);
    pinMode(ledDrums[i], OUTPUT);
  }

  digitalWrite(closedHatGate, HIGH); 
  
  Serial.begin(31250); // Initialize MIDI hardware UART

  startupAnimation();

  byte savedLen = EEPROM.read(0);
  if (savedLen >= 1 && savedLen <= 16) seqLength = savedLen;

  int addr = 1;
  for (int v = 0; v < 4; v++) {
    for (int s = 0; s < 16; s++) {
      byte val = EEPROM.read(addr++);
      pattern[v][s] = (val == 1);
    }
  }
  savedPotVal = analogRead(potTempo);
}

void loop() {
  unsigned long currentMillis = millis();
  bool shiftHeld = (digitalRead(btnShift) == LOW);

  handleMIDI();
  handleSequencerTick(currentMillis);
  handleTriggers(currentMillis);
  handleButtons(shiftHeld, currentMillis);
  handleTempoAndSwing(shiftHeld);
  updateLEDs(currentMillis, shiftHeld);
}

// --- HIGH-SPEED MIDI HANDLER (PURE SOUND MODULE MODE) ---
void handleMIDI() {
  while (Serial.available() > 0) {
    byte incomingByte = Serial.read();

    // 1. RUTHLESS SYSTEM FILTER
    // 0xF8 to 0xFF are System Real-Time messages (Clock, Start, Stop, Active Sensing).
    // By instantly calling 'continue', we throw ALL of them in the trash!
    if (incomingByte >= 0xF8) {
      continue; 
    }

    // 2. CHANNEL FILTER
    // We ONLY care about Note On for Channel 10 (0x99). 
    if (incomingByte >= 0x80) {
      if (incomingByte == 0x99) {
        midiCommand = incomingByte;
        midiState = 1; // Open the gate: we are ready to read the note!
      } else {
        midiState = 0; // Close the gate! Ignore this status and all its data bytes.
      }
    } 
    // 3. PROCESS THE DATA BYTES (Only if the gate is open for Ch 10)
    else if (midiState == 1) {
      midiNote = incomingByte;
      midiState = 2;
    } 
    else if (midiState == 2) {
      midiVelocity = incomingByte;
      midiState = 1; // Reset to 1 for "Running Status" (rapid-fire notes)

      // Fire the analog triggers!
      if (midiVelocity > 0) {
        if (midiNote == 36) fireTrigger(0, true);      // Kick (C2)
        else if (midiNote == 38) fireTrigger(1, true); // Snare (D2)
        else if (midiNote == 44) fireTrigger(2, true); // CHH (G#2)
        else if (midiNote == 46) fireTrigger(3, true); // OHH (A#2)
      }
    }
  }
}

// --- CORE SEQUENCER ---
void handleSequencerTick(unsigned long currentMillis) {
  // Auto-fallback to internal clock if MIDI is unplugged for 500ms
  if (useExternalClock && (currentMillis - lastMidiClockTime > 500)) {
    useExternalClock = false;
  }

  // If external MIDI is driving us, ignore the internal timer!
  if (useExternalClock || !isPlaying) return;

  unsigned long currentInterval = stepInterval;
  if (currentStep % 2 != 0) currentInterval += (stepInterval * swingAmount) / 100;
  else currentInterval -= (stepInterval * swingAmount) / 100;

  if (currentMillis - lastStepTime >= currentInterval) {
    lastStepTime += currentInterval; 
    playCurrentStepAndAdvance();
  }
}

void playCurrentStepAndAdvance() {
  digitalWrite(syncOut, LOW); 
  syncTriggerActive = true;
  syncTriggerStartTime = millis();
  
  for (int i = 0; i < 4; i++) {
    if (pattern[i][currentStep]) {
      if (i == 3 && pattern[2][currentStep]) continue; 
      fireTrigger(i, false); 
    }
  }
  
  currentStep++;
  if (currentStep >= seqLength) currentStep = 0;
}

// --- HARDWARE TRIGGERS ---
void fireTrigger(int voice, bool isManual) {
  if (!isManual && muted[voice]) return; 

  if (voice == 0) digitalWrite(kickOut, HIGH);
  else if (voice == 1) digitalWrite(snareOut, HIGH);
  else if (voice == 2) {
    gateClosed = true;
    digitalWrite(closedHatGate, HIGH);
    digitalWrite(hihatOut, HIGH);
  }
  else if (voice == 3) {
    gateClosed = false;
    digitalWrite(closedHatGate, LOW);
    digitalWrite(hihatOut, HIGH);
  }
  
  triggerActive[voice] = true;
  triggerStartTime[voice] = millis();
  
  if (!isManual) {
    visualTriggerTime[voice] = millis(); 
  }
}

void handleTriggers(unsigned long currentMillis) {
  for (int i = 0; i < 4; i++) {
    if (triggerActive[i] && (currentMillis - triggerStartTime[i] >= TRIG_LEN)) {
      triggerActive[i] = false;
      if (i == 0) digitalWrite(kickOut, LOW);
      else if (i == 1) digitalWrite(snareOut, LOW);
      else if (i == 2 || i == 3) digitalWrite(hihatOut, LOW);
    }
  }
  digitalWrite(closedHatGate, gateClosed ? HIGH : LOW);

  if (syncTriggerActive && (currentMillis - syncTriggerStartTime >= TRIG_LEN)) {
    syncTriggerActive = false;
    digitalWrite(syncOut, HIGH); 
  }
}

// --- EEPROM SAVE HELPERS ---
void saveStepToEEPROM(int voice, int step, bool state) {
  int addr = 1 + (voice * 16) + step;
  EEPROM.update(addr, state ? 1 : 0);
}

void saveFullPatternToEEPROM() {
  int addr = 1;
  for (int v = 0; v < 4; v++) {
    for (int s = 0; s < 16; s++) {
      EEPROM.update(addr++, pattern[v][s] ? 1 : 0);
    }
  }
}

// --- BUTTON LOGIC ---
void handleButtons(bool shiftHeld, unsigned long currentMillis) {
  bool playPressed = (digitalRead(btnPlay) == LOW);
  bool leftPressed = (digitalRead(btnLeft) == LOW);
  bool rightPressed = (digitalRead(btnRight) == LOW);

  if (playPressed && !lastPlay && (currentMillis - lastNavTime > DEBOUNCE_DELAY)) {
    if (shiftHeld) {
      isLiveMode = !isLiveMode;
      showingMode = true;
      modeShowTimer = currentMillis;
      modeScrollDir = isLiveMode; 
    } else {
      isPlaying = !isPlaying;
      if (isPlaying) { 
        currentStep = 0; 
        lastStepTime = currentMillis; 
      }
    }
    lastNavTime = currentMillis;
  }
  lastPlay = playPressed;

  if (!isLiveMode) {
    if (leftPressed && !lastLeft && (currentMillis - lastNavTime > DEBOUNCE_DELAY)) {
      if (shiftHeld) {
        currentPage = (currentPage - 1 + 4) % 4;
        showPageSelect(currentMillis);
      } else {
        currentVoice = (currentVoice - 1 + 4) % 4;
        showVoiceSelect(currentMillis); 
      }
      lastNavTime = currentMillis;
    }
    
    if (rightPressed && !lastRight && (currentMillis - lastNavTime > DEBOUNCE_DELAY)) {
      if (shiftHeld) {
        currentPage = (currentPage + 1) % 4;
        showPageSelect(currentMillis);
      } else {
        currentVoice = (currentVoice + 1) % 4;
        showVoiceSelect(currentMillis); 
      }
      lastNavTime = currentMillis;
    }
  }
  lastLeft = leftPressed;
  lastRight = rightPressed;

  bool allPressed = true;
  for (int i = 0; i < 4; i++) {
    bool drumPressed = (digitalRead(btnDrums[i]) == LOW);
    if (!drumPressed) allPressed = false;

    if (drumPressed && !lastDrums[i] && (currentMillis - lastDrumTime[i] > DEBOUNCE_DELAY)) {
      if (isLiveMode) {
        if (shiftHeld) {
          muted[i] = !muted[i]; 
        } else {
          fireTrigger(i, true); 
        }
      } else {
        if (shiftHeld) {
          muted[i] = !muted[i]; 
        } else {
          int stepIndex = (currentPage * 4) + i;
          pattern[currentVoice][stepIndex] = !pattern[currentVoice][stepIndex];
          saveStepToEEPROM(currentVoice, stepIndex, pattern[currentVoice][stepIndex]);
        }
      }
      lastDrumTime[i] = currentMillis;
    }
    lastDrums[i] = drumPressed;
  }

  // GLOBAL ACTIONS (Shift + All 4 Buttons)
  if (shiftHeld && allPressed && !allPressedHandled) {
    if (!isLiveMode) {
      clearPatternAnimation();
      for (int v = 0; v < 4; v++) {
        for (int s = 0; s < 16; s++) pattern[v][s] = false;
        muted[v] = false; 
      }
      saveFullPatternToEEPROM();
      
      // Reset de UI view naar Kick en Pagina 1
      currentVoice = 0; 
      currentPage = 0;  
    } 
    allPressedHandled = true;
  } else if (!allPressed) {
    allPressedHandled = false;
  }
}

// --- TEMPO, SWING & LENGTH (PRO SOFT-TAKEOVER) ---
void handleTempoAndSwing(bool shiftHeld) {
  int potVal = analogRead(potTempo);
  bool leftHeld = (digitalRead(btnLeft) == LOW);
  bool rightHeld = (digitalRead(btnRight) == LOW);
  
  bool lengthEditActive = (!isLiveMode && shiftHeld && leftHeld && rightHeld);

  if (shiftHeld && !lastShiftState) swingLocked = true;
  if (!shiftHeld && lastShiftState) tempoLocked = true;
  lastShiftState = shiftHeld;

  if (lengthEditActive && !lastLengthEditState) lengthLocked = true;
  lastLengthEditState = lengthEditActive;

  if (lengthEditActive) {
    if (lengthLocked) {
      int potLen = map(potVal, 0, 1023, 16, 1);
      if (abs(potLen - seqLength) <= 1) lengthLocked = false;
    }

    if (!lengthLocked) {
      int newLen = map(potVal, 0, 1023, 16, 1);
      if (newLen != seqLength) {
        seqLength = newLen;
        EEPROM.update(0, seqLength);
      }
    }
    
    swingLocked = true; 
    wasShiftHeldForPot = true;
    return;
  }

  if (shiftHeld) {
    if (swingLocked) {
      int potSwing = map(potVal, 0, 1023, 50, 0);
      if (abs(potSwing - swingAmount) <= 2) swingLocked = false;
    }
    
    if (!swingLocked) {
      swingAmount = map(potVal, 0, 1023, 50, 0);
    }
    wasShiftHeldForPot = true;
  } else {
    if (tempoLocked) {
      int potBpm = map(potVal, 0, 1023, 160, 40);
      int currentBpm = 15000 / stepInterval;
      if (abs(potBpm - currentBpm) <= 3) tempoLocked = false;
    }
    
    if (!tempoLocked) {
      int bpm = map(potVal, 0, 1023, 160, 40);
      stepInterval = 15000 / bpm; 
    }
  }
}

// --- UI ANIMATIONS & LEDS ---
void fadeTransition(int ledOut1, int ledIn1, int ledOut2 = -1, int ledIn2 = -1) {
  for (int i = 0; i <= 255; i += 5) { 
    if (ledOut1 >= 0) analogWrite(ledDrums[ledOut1], 255 - i);
    if (ledIn1 >= 0) analogWrite(ledDrums[ledIn1], i);
    if (ledOut2 >= 0) analogWrite(ledDrums[ledOut2], 255 - i);
    if (ledIn2 >= 0) analogWrite(ledDrums[ledIn2], i);
    delay(3); 
  }
}

void startupAnimation() {
  for (int i = 0; i < 4; i++) analogWrite(ledDrums[i], 0);
  fadeTransition(-1, 0); 
  fadeTransition(0, 1);  
  fadeTransition(1, 2);  
  fadeTransition(2, 3);  
  fadeTransition(-1, 0);       
  fadeTransition(0, 1, 3, 2);  
  fadeTransition(1, 0, 2, 3);  
  fadeTransition(3, -1);       
  fadeTransition(0, 1);  
  fadeTransition(1, 2);  
  fadeTransition(2, 3);  
  fadeTransition(3, -1); 
}

void showVoiceSelect(unsigned long currentMillis) {
  showingVoice = true;
  voiceShowTimer = currentMillis;
}

void showPageSelect(unsigned long currentMillis) {
  showingPage = true;
  pageShowTimer = currentMillis;
}

void clearPatternAnimation() {
  for (int blink = 0; blink < 3; blink++) {
    for (int i = 0; i < 4; i++) analogWrite(ledDrums[i], LED_BRIGHT);
    delay(100);
    for (int i = 0; i < 4; i++) analogWrite(ledDrums[i], 0);
    delay(100);
  }
}

void updateLEDs(unsigned long currentMillis, bool shiftHeld) {
  if (showingMode) {
    unsigned long elapsed = currentMillis - modeShowTimer;
    if (elapsed < 240) { 
      int ledIndex = elapsed / 60; 
      if (modeScrollDir) ledIndex = 3 - ledIndex; 
      
      for (int i = 0; i < 4; i++) {
        if (i == ledIndex) analogWrite(ledDrums[i], LED_BRIGHT);
        else analogWrite(ledDrums[i], 0);
      }
      return; 
    } else {
      showingMode = false;
    }
  }

  bool leftHeld = (digitalRead(btnLeft) == LOW);
  bool rightHeld = (digitalRead(btnRight) == LOW);
  if (!isLiveMode && shiftHeld && leftHeld && rightHeld) {
    int lenPage = (seqLength - 1) / 4;
    int lenStep = (seqLength - 1) % 4;
    for (int i = 0; i < 4; i++) {
      if (i == lenStep) analogWrite(ledDrums[i], LED_BRIGHT);
      else if (i == lenPage) analogWrite(ledDrums[i], LED_DIM);
      else analogWrite(ledDrums[i], 0);
    }
    return;
  }

  if (showingVoice) {
    if (currentMillis - voiceShowTimer < 300) {
      bool flashState = ((currentMillis - voiceShowTimer) % 100) < 50; 
      for (int i = 0; i < 4; i++) {
        if (i == currentVoice && flashState) analogWrite(ledDrums[i], LED_BRIGHT);
        else analogWrite(ledDrums[i], 0);
      }
      return;
    } else {
      showingVoice = false;
    }
  }

  if (showingPage) {
    if (currentMillis - pageShowTimer < 400) {
      for (int i = 0; i < 4; i++) {
        if (i == currentPage) analogWrite(ledDrums[i], LED_BRIGHT);
        else analogWrite(ledDrums[i], 0);
      }
      return;
    } else {
      showingPage = false;
    }
  }

  if (isLiveMode) {
    for (int i = 0; i < 4; i++) {
      if (digitalRead(btnDrums[i]) == LOW) {
        analogWrite(ledDrums[i], LED_BRIGHT);
      } else if (currentMillis - visualTriggerTime[i] < 50) {
        analogWrite(ledDrums[i], LED_DIM);
      } else {
        analogWrite(ledDrums[i], 0);
      }
    }
  } else {
    int playheadPage = currentStep / 4;
    int playheadLedIndex = currentStep % 4;

    for (int i = 0; i < 4; i++) {
      int absoluteStep = (currentPage * 4) + i;
      
      if (isPlaying && (currentPage == playheadPage) && (i == playheadLedIndex)) {
        analogWrite(ledDrums[i], LED_BRIGHT);
      } else if (pattern[currentVoice][absoluteStep]) {
        analogWrite(ledDrums[i], LED_DIM);
      } else {
        analogWrite(ledDrums[i], 0);
      }
    }
  }
}
